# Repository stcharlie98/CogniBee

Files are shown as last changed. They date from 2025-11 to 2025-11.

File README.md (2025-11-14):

# CogniBee  
Trabalho de Conclusão de Curso (Projeto CogniBee)










---

## Visão Geral

O CogniBee é um sistema de monitoramento para colmeias que integra sensores, firmware modular, conectividade e um conjunto de modelos 2D/3D e PCB desenvolvidos especificamente para o protótipo.  
O sistema registra temperatura, umidade e peso da colmeia, permitindo análises contínuas com baixo consumo de energia através de deep sleep programável.

Este repositório reúne o firmware do ESP32, modelos mecânicos, arquivos da PCB e uma versão anterior do site usado para visualização de dados.

---

## Funcionalidades Principais

- Medição de temperatura e umidade (DHT22)  
- Medição de peso com célula de carga + HX711  
- Envio de telemetria via MQTT/Blynk  
- Gerenciamento de energia com deep sleep  
- Arquitetura modular do firmware  
- Estrutura física compacta adaptada ao interior da colmeia  
- PCB projetada para o protótipo (Rev. 3.0)

---

## Como usar o código Arduino

A pasta `/Arduino Code/mainCode` contém o firmware modular do ESP32.

### 1. Requisitos

- ESP32 DevKit  
- Arduino IDE 2.x  
- Bibliotecas necessárias:  
  - DHT sensor library  
  - Adafruit Unified Sensor  
  - HX711  
  - WiFi (nativa)  
  - Blynk ou PubSubClient  

### 2. Configuração

No arquivo `config.h`, ajuste:

- Pinos do DHT22  
- Pinos do HX711  
- Fator de calibração da balança  
- Intervalos de deep sleep  

No arquivo `credentials.h`, informe:

- Wi-Fi SSID e senha  
- Token Blynk ou parâmetros MQTT

### 3. Upload

1. Abra a Arduino IDE  
2. Vá em **Arquivo > Abrir** e selecione o diretório `mainCode`  
3. Em **Ferramentas**, selecione:  
   - Placa: **ESP32 Dev Module**  
   - Porta correspondente  
4. Clique em **Upload**

Após o envio, o ESP32 executará automaticamente o ciclo de leitura → transmissão → deep sleep.

---

## Estrutura do Repositório

/Arduino Code
mainCode/ → Firmware do ESP32
/AutoCAD 2D → Desenhos estruturais
/Fusion → Modelos 3D
/PCB → Projeto da PCB (Rev. 3.0)
/Website → Versão antiga do site
LICENSE
README.md

yaml
Copy code

---

## Tecnologias Utilizadas

- ESP32 – Firmware em C++  
- MQTT / Blynk  
- AutoCAD 2D  
- Fusion 360  
- Software de EDA para PCB  
- HTML/CSS/JS (versão antiga do site)

---

## Licença

Distribuído sob a licença MIT.

---

# 🇺🇸 README — English Version

# CogniBee  
Intelligent Beehive Monitoring System










---

## Overview

CogniBee is an embedded monitoring system for beehives combining sensors, modular firmware, IoT communication and custom PCB and mechanical design.  
It records temperature, humidity and weight, operating with low power consumption through a deep sleep routine optimized for field use.

This repository contains the ESP32 firmware, mechanical models, PCB files and an older version of the website used for data display.

---

## Key Features

- Temperature and humidity measurement (DHT22)  
- Weight measurement using load cell + HX711  
- MQTT/Blynk telemetry  
- Deep sleep power management  
- Modular firmware structure  
- Mechanical design adapted for hive installation  
- Custom PCB (Rev. 3.0)

---

## How to Use the Arduino Code

The ESP32 firmware is located in `/Arduino Code/mainCode`.

### 1. Requirements

- ESP32 DevKit  
- Arduino IDE 2.x  
- Required libraries:  
  - DHT sensor library  
  - Adafruit Unified Sensor  
  - HX711  
  - WiFi (built-in)  
  - Blynk or PubSubClient  

### 2. Configuration

In `config.h`, set:

- DHT22 pins  
- HX711 pins  
- Load cell calibration factor  
- Deep sleep intervals  

In `credentials.h`, set:

- Wi-Fi SSID and password  
- Blynk token or MQTT credentials

### 3. Upload

1. Open Arduino IDE  
2. Load the `mainCode` directory  
3. Select:  
   - Board: **ESP32 Dev Module**  
   - Correct COM port  
4. Click **Upload**

The ESP32 will automatically run the read → publish → deep sleep cycle.

---

## Repository Structure

/Arduino Code
mainCode/ → ESP32 firmware
/AutoCAD 2D → Structural drawings
/Fusion → Mechanical models
/PCB → PCB layout (Rev. 3.0)
/Website → Old version of the website
LICENSE
README.md

yaml
Copy code

---

## Technologies Used

- ESP32 (C++)  
- MQTT / Blynk  
- AutoCAD 2D  
- Fusion 360  
- PCB EDA tools  
- HTML/CSS/JS (legacy website)

---

## License

Released under the MIT License.

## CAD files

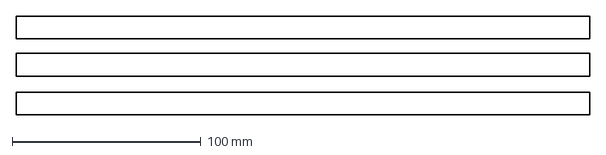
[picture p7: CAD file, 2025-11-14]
AutoCAD 2D/Caixa dos favos - MDF - 3mm.dxf
304.0 x 52.1 mm

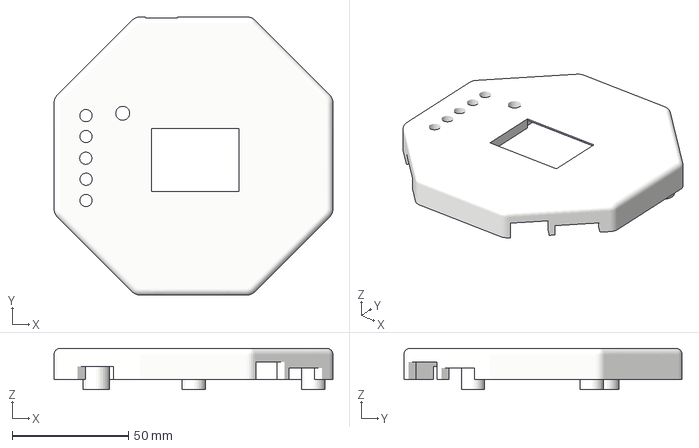
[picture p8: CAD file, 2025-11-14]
Fusion/Tampa_Exterior.3mf
120.2 x 119.9 x 17.8 mm

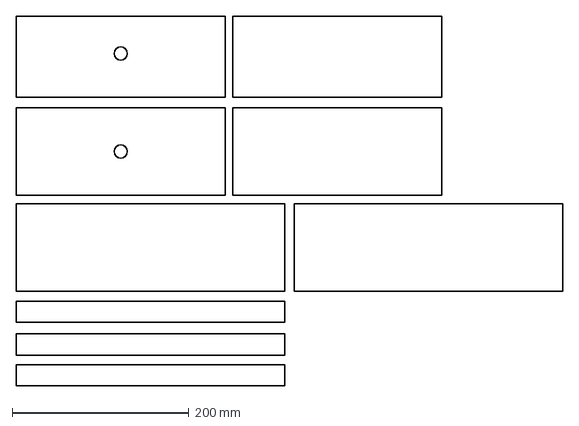
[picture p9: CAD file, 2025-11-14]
AutoCAD 2D/Caixa dos favos - MDF - 6mm.dxf
619.2 x 418.9 mm

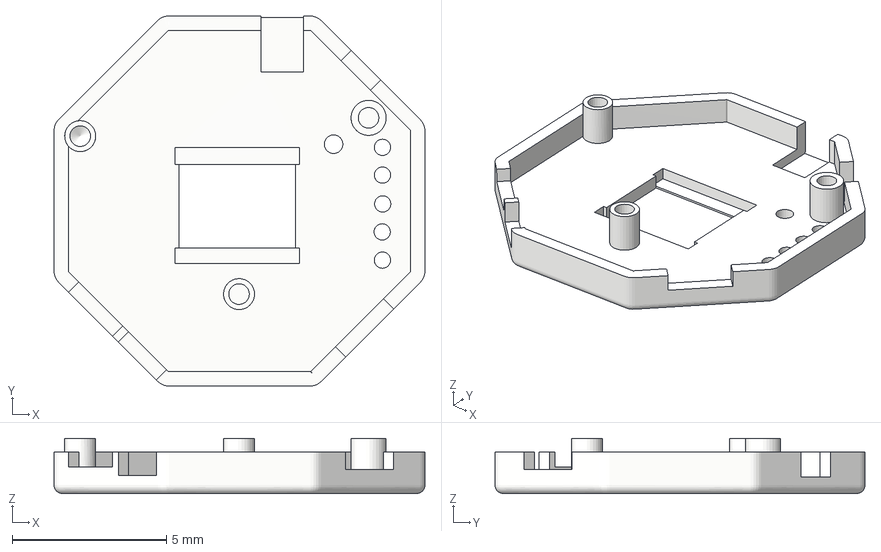
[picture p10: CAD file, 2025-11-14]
Fusion/Tampa_Interior.3mf
12.0 x 12.0 x 1.78 mm

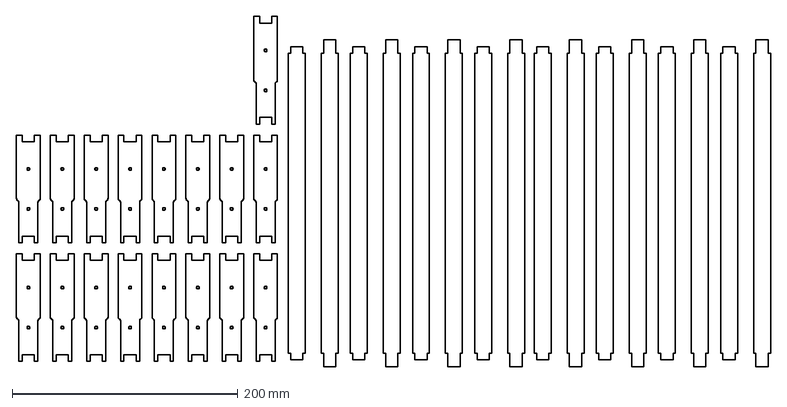
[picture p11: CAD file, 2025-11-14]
AutoCAD 2D/Favo - MDF - 6mm.dxf
667.3 x 309.9 mm

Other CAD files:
AutoCAD 2D/2D_Design.dwg

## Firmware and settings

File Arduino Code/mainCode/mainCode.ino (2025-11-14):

/**
 * @file mainCode.ino
 * @brief Arquivo principal do firmware CogniBee (protótipo de bancada).
 *
 * Responsabilidades:
 * - Inicializar sensores e comunicação
 * - Coletar um conjunto de medições
 * - Enviar telemetria ao servidor
 * - Avaliar condições críticas (variação de peso)
 * - Entrar em deep sleep pelo intervalo adequado
 *
 * Observações:
 * 1. Este firmware executa apenas um ciclo por boot. O ESP32 reinicia
 * automaticamente ao sair do deep sleep, repetindo o processo;
 * 2. Este firmware é otimizado para prototipagem e testes de bancada;
 * 3. A versão final para a PCB (Rev 3.0) compartilha a mesma lógica,
 * mudando apenas os pinos definidos em config.h.
 */

#include "config.h"
#include "credentials.h"
#include "comms.h"
#include "sensors.h"
#include "publisher.h"
#include "SleepManager.h"

void setup() {
  Serial.begin(115200);
  Serial.println("\n[CogniBee] Inicializando sistema...");

  // Inicialização dos módulos
  Sensors_begin();
  Comms_begin();

  // Inicializa o gerenciador de sono com o intervalo padrão (30 minutos)
  SleepManager_begin(DEFAULT_SLEEP_INTERVAL_SEC);

  Serial.println("\n[CogniBee] Sistema inicializado.");
  Serial.println("\n[CogniBee] Executando ciclo de medição...");

  // Leituras
  Telemetria dados = Sensors_coletar();

  // Envio para o servidor
  Publisher_enviar(dados);

  // Atualiza lógica de alerta com base na variação de peso
  SleepManager_updateWeightAndDecide(dados.peso_kg);
  
  unsigned long sleepSeconds = SleepManager_getNextSleepInterval();
  Serial.print("\n[CogniBee] Entrando em deep sleep por ");
  Serial.print(sleepSeconds);
  Serial.println(" segundos.");

  // Aguarda flush de logs e operações pendentes
  delay(200);

  // Entra no deep sleep pelo intervalo calculado
  SleepManager_enterDeepSleep(sleepSeconds);
}

void loop() {
  // Loop não é utilizado, pois a lógica do CogniBee é 100% baseada em deep sleep.
}

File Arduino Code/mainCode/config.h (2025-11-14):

#pragma once

// -------------------------
// Pinagem do Protótipo
// -------------------------
#define PIN_DHT_DATA   27
#define PIN_HX711_DT   12
#define PIN_HX711_SCK  14

// -------------------------
// Configurações do DHT
// -------------------------
#define DHT_TYPE DHT22

// -------------------------
// Calibração da célula de carga
// (obtida experimentalmente)
// -------------------------
#define CALIBRATION_FACTOR 46.18f
#define HX711_SAMPLES 10

// -------------------------
// Timer de leitura
// -------------------------
#define SENSOR_READ_INTERVAL_MS 5000

// -------------------------
// Pinos Virtuais do Blynk
// -------------------------
#define VPIN_PESO         V0
#define VPIN_TEMPERATURA  V1
#define VPIN_UMIDADE      V2

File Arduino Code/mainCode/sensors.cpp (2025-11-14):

#include "sensors.h"
#include "config.h"
#include <DHT.h>
#include <HX711.h>

static DHT dht(PIN_DHT_DATA, DHT_TYPE);
static HX711 hx;

// Inicialização dos sensores
void Sensors_begin() {
  Serial.println("[Sensores] Inicializando...");

  dht.begin();
  hx.begin(PIN_HX711_DT, PIN_HX711_SCK);

  if (hx.is_ready()) {
    hx.set_scale(CALIBRATION_FACTOR);
    hx.tare();
    Serial.println("[Sensores] HX711 pronto e tarado.");
  } else {
    Serial.println("[ERRO] HX711 não encontrado. Travando.");
    while (1);
  }
}

// Coleta os dados e retorna uma struct
Telemetria Sensors_coletar() {
  Telemetria t;

  t.peso = hx.get_units(HX711_SAMPLES) / 1000.0f;
  t.temp = dht.readTemperature();
  t.umid = dht.readHumidity();

  if (isnan(t.temp) || isnan(t.umid)) {
    Serial.println("[Aviso] Falha no DHT22. Mantendo última leitura válida.");
  }

  return t;
}

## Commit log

2025-11-14 Create PCB
2025-11-14 Add files via upload
    PCB files created in Altium Designer.
    [CogniBee.PrjPCB, CogniBee_V2_0_Título.SchDoc, CogniBee_V2_1_CPU.SchDoc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]
2025-11-14 Add files via upload
    Mechanical enclosure made in Fusion for the PCB.
    [Tampa_Exterior.3mf, Tampa_Interior.3mf]
2025-11-14 Add files via upload
    2D designs made in AutoCAD for the beehive.
    [2D_Design.dwg, Caixa dos favos - MDF - 3mm.dxf, Caixa dos favos - MDF - 6mm.dxf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]
2025-11-14 Add files via upload
    Firmware made in Arduino IDE for the PCB.

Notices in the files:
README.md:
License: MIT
